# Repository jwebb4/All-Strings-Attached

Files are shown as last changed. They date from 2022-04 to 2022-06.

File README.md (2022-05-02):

# All-Strings-Attached
Senior Design Project under Dr. Abbott

Sponsership: Phil Westhart

### Team Members
Fall 2021 - Spring 2022: Carlos Rosales-Moran, Kimberly Tse, Joshua Webb

## Objective
**End Goal:** 
Determine the lifespan of strings on a string instrument
- First Iteration (Fall 2021-Spring 2022): Data Collection, provide foundation of mobile applicaiton

## Resources
**Mobile Application**
- ReactNative
- Expo Simulator (for debugging purposes)

**Microcontroller Programming**
- ArduinoIDE
- Special thanks to Neil Kolban for providing BLE libraries for the ESP32: Check out his repository: https://github.com/nkolban

## How to Use
Have the following in hand - we'll provide the documentation of how to set up
- Firebeetle IoT ESP32
- Wires & solder
- Wire stripper/cutter
- Pliers
- Proto-boards (optional)
- Tilt sensors
- AllStringsAttached mobile application

**Microcontroller SOFTWARE**
1. Download "All_Code_Put_Togehter.ino" into your desired directory. Make sure that it is nested underneath the folder with the same name.
2. Open the program using Arduino IDE
3. Compile & run :)

**Microcontroller HARDWARE**
1. Refer to the circuit schematic uploaded into this repo
2. Make sure to test each wiring when you solder. You can use a circuitboard to see whether it works!
3. Follow the circuit schematic and put the components together

**Microcontroller and Mobile Application **
1. Use the BLE scanner to check for the "Strings attached" device
2. Have fun!

## Future Implementation
- Update GUI of mobile application
- Collect data & attributes
- Develop string life prediction algorithm

## Acknowledgements
We would like to extend our deepest gratitude to those who have mentored, inspired, and/or guided us throughout this year-long project. We would like to first thank Dr. Rezaie for their mentorship and advice throughout the year, engineering technician Mr. Vernon Weir and Ms. Nicole Webb, and administrative coordinator Ms. Gail Jaszcz for helping us with the materials and operations of building our prototypes. We would also like to thank Mr. Don Bustos and Mr. Kevin Mendoza for their donation of strings.

Our deepest thanks to our customer, Phil Westhart, for providing the opportunity of implementing this project and for sharing his knowledge, guidance, and funding. Similarly, we would like to thank our mentor, Dr. Abbott, for guiding us throughout the project’s lifespan and for sharing the knowledge he has gained through several years of industry experience. Finally, we would like to thank all the other professors, students, and everyone that have shared their invaluable knowledge with us, since without them, we would not have sufficient knowledge to undergo this project.

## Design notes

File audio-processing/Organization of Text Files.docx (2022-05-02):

# Organization of Text Files

**Feel free to change naming – the attributes are harder to change tho.

# Naming

Ex. old-11282021-g.txt

- These are old strings (used and taken off from strings). You can change it to be something else.
- The recording is done on 11-28-2021
- We have a recording of the g string

# Attributes (What is inside the text files)

- instrument_type – What instrument is it? (Violin, viola, guitar, mandolin, etc.)
- instrument_size – What size is the instrument (Full size is 4/4 for violins, 7/8, ¾, etc.)
- num_strings_hold – How many strings does this instrument hold
- pitch – What is the letter sound of the pitch? (Middle C is C4, G3, A5, etc.)
- frequency – At what frequency is the pitch?
  - ** Sometimes they are tuned at the relative same pitch, but different frequencies. Some orchestras for example sometimes use 440Hz for an A, while others uses a 442Hz.
- string_core – What is the core of the string? (Synthetic, nylon, gut, steel, etc.)
- string_winding – If applicable, what winding around the core is the material? (Aluminum, silver, etc.)
- string_brand – What brand/company is the string from? (Pirastro, Thomastik, D’Addario)
- string_brand_version – From that string company, what string ‘version’ is it? (ProArte is made from D’ Addario, Vision Solos is made from Thomastik)
- string_guage – What is the tension of the strings (if applicable) (Options are light, medium, heavy)
- string_guage_value – What is the value of the string tension (per LBS)
- total_practice_time -- At the time of recording, how long were the strings practiced on?
- date_manufactured – When was this string manufactured? If applicable
- date_string_placed – When was this string placed onto the instrument?
- time_since_string_placed – How long has the strings been on the instrument
- has_capo – Does the instrument had a clip where it temporarily changes the pitch of the string (guitar) (Use 0 for no, 1 for yes)
- playing_style – What style is the instrument primarily played in
- percentage_other – How much do you think the string was played with an object? (bow, guitar pick, etc.)
- percentage_fingers – How much do you think the string was played with your fingers (plucking, strumming, etc.)
- sound_type – what kind of sound is being played in the audio? (Arco – long bow stroke, Pizz -- plucking sound)

All Strings Attached

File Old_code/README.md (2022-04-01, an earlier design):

This folder contains all the past versions of code and the parts of code which 
the current full version of this project are made of.

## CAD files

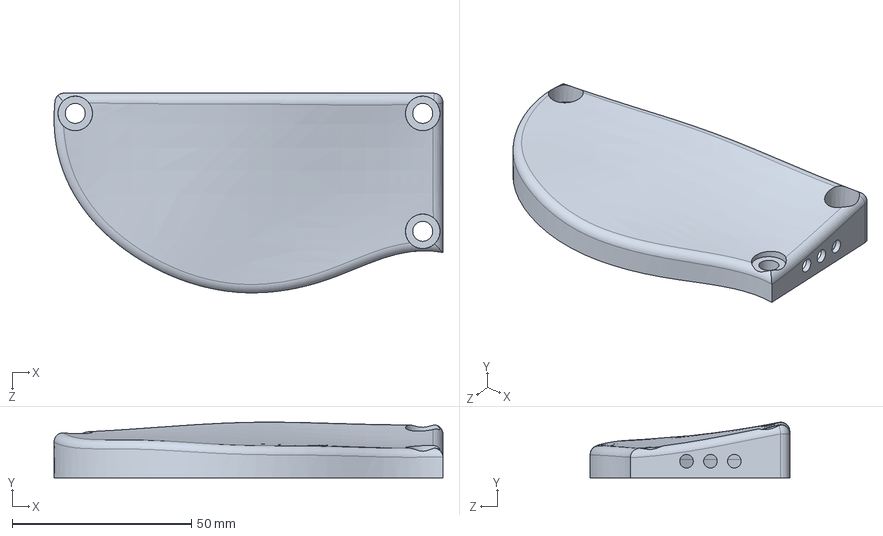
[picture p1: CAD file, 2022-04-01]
Current model curved lid/Model of thin curved lid.SLDPRT
108.5 x 15.6 x 55.7 mm

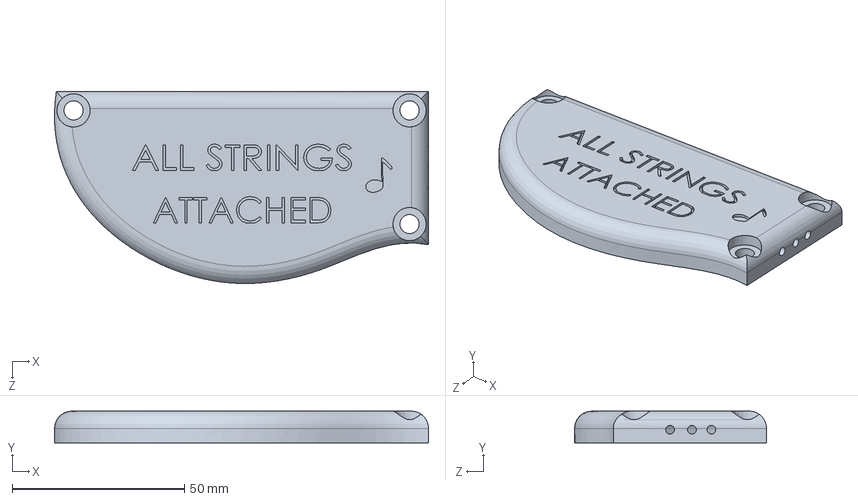
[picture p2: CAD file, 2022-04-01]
Current Model flat lid/model with flat thin lid.SLDPRT
108.5 x 9.21 x 55.7 mm

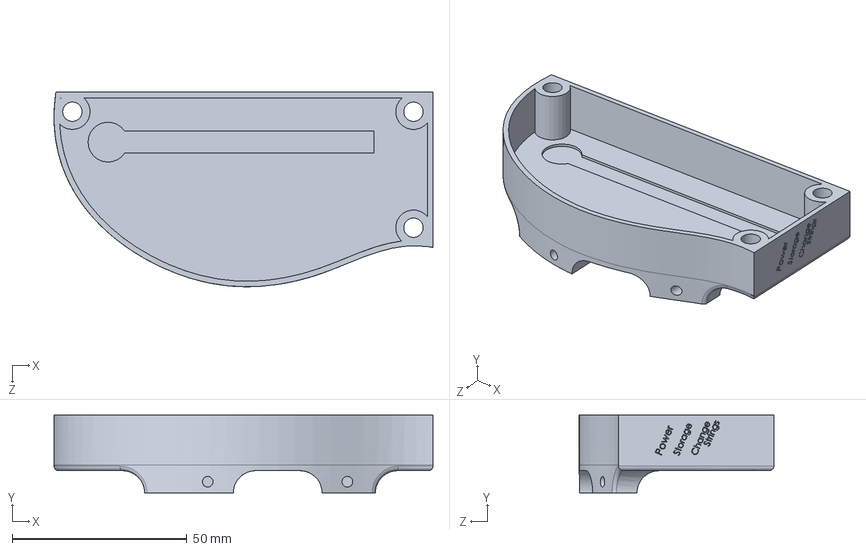
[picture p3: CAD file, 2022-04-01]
Current model curved lid/Model of base of device.SLDPRT
108.5 x 22.2 x 55.7 mm

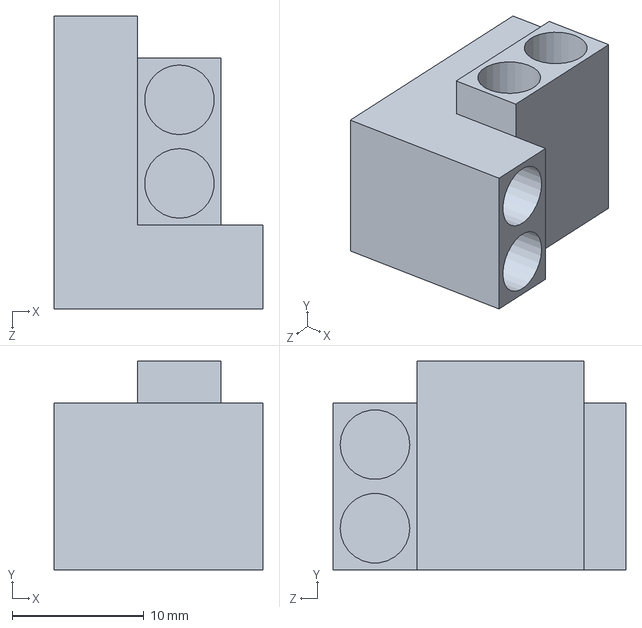
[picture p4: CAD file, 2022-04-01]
Current Model flat lid/tilt sensor holder.SLDPRT
15.9 x 15.9 x 22.2 mm

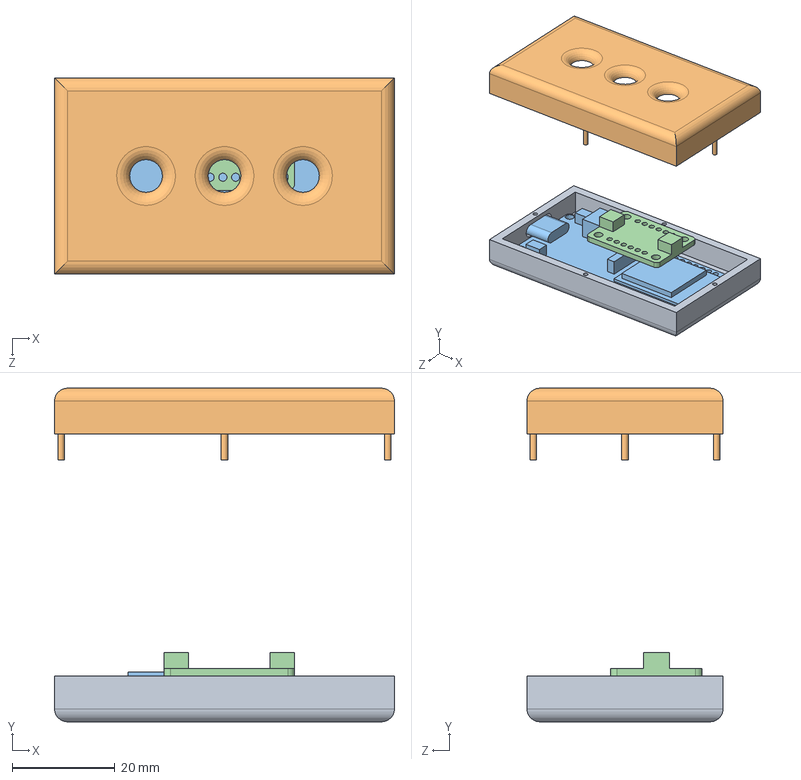
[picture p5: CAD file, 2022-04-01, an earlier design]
Old_models/First model/BoxAssembly.SLDASM
66.0 x 64.8 x 38.1 mm
Box-Bottom
Box-Top
micro
Accelerometer

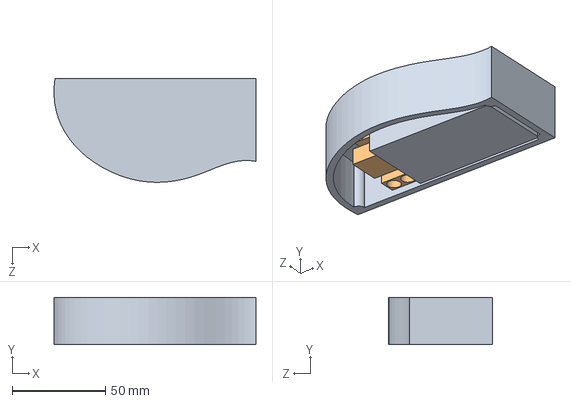
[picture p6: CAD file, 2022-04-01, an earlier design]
Old_models/Fourth model/start of fitting parts.SLDASM
108.5 x 25.4 x 55.7 mm
New device
tilt sensor holder

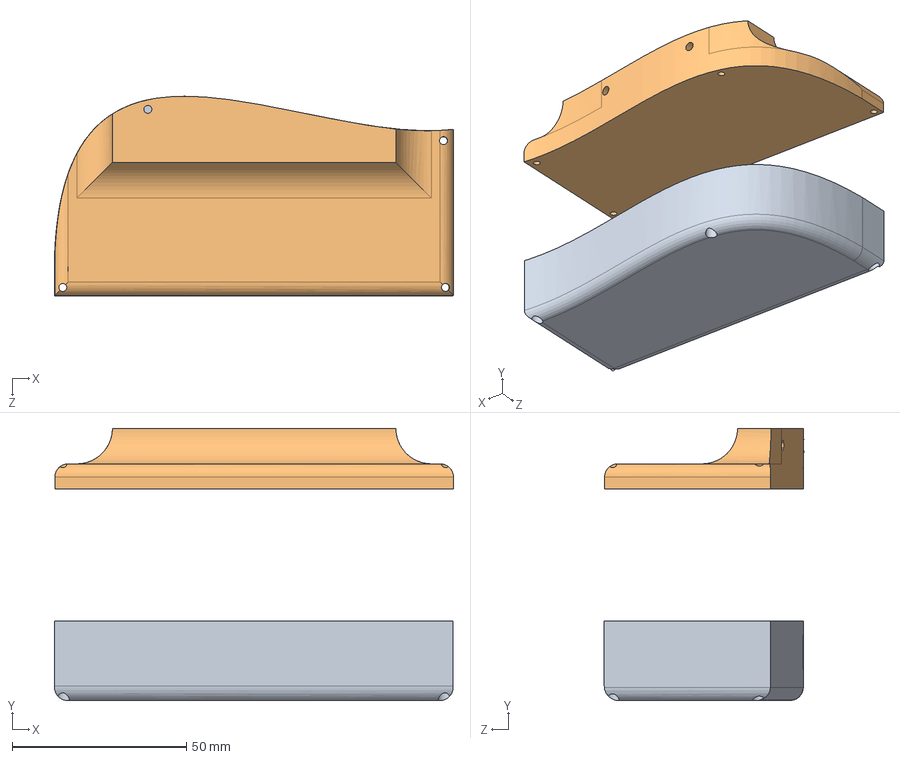
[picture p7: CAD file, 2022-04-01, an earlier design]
Old_models/Third model/device assembly.SLDASM
114.4 x 78.0 x 57.2 mm
device housing
Lid of device

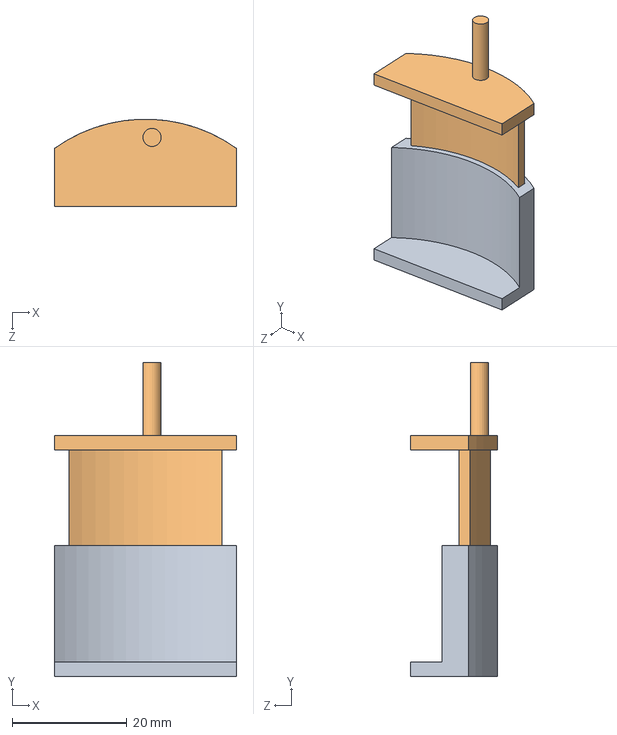
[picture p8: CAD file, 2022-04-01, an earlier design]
Old_models/First model/ClampAssembly.SLDASM
31.8 x 54.7 x 15.2 mm
Clamp-Bottom
Clamp-Top

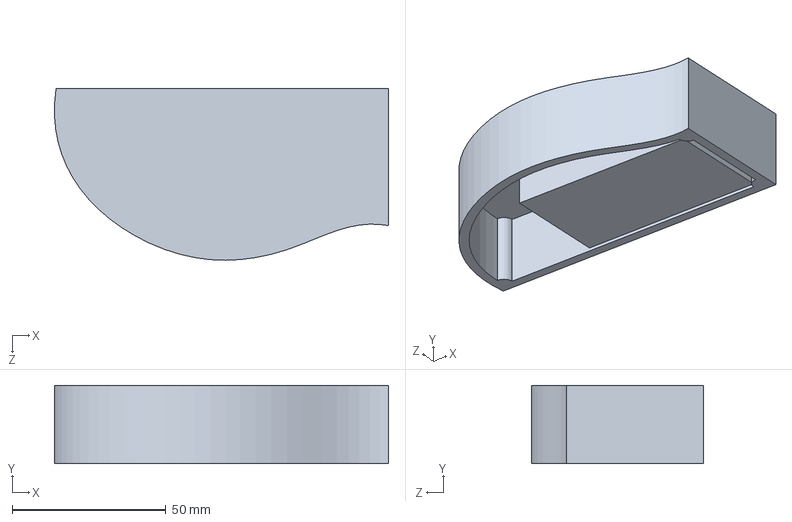
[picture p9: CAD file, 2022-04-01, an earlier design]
Old_models/Fourth model/New device.SLDPRT
108.5 x 25.4 x 55.7 mm

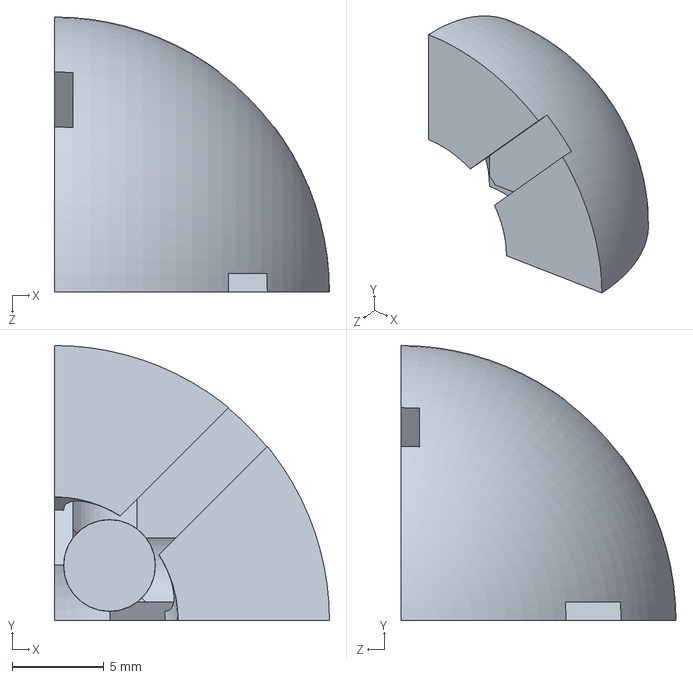
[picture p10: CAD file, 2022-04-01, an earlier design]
Old_models/Initial parts/Tilt sensor holder.SLDPRT
15.0 x 15.0 x 15.0 mm

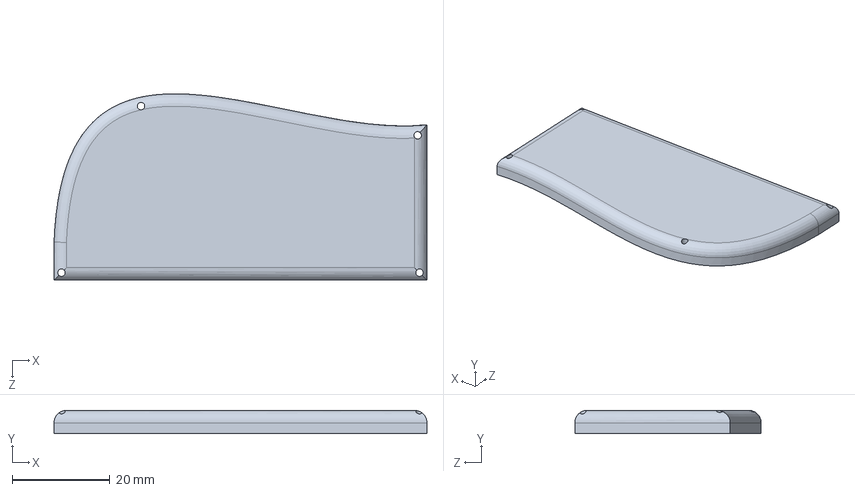
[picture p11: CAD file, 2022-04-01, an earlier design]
Old_models/Second model/Lid of device.SLDPRT
76.2 x 4.76 x 38.1 mm

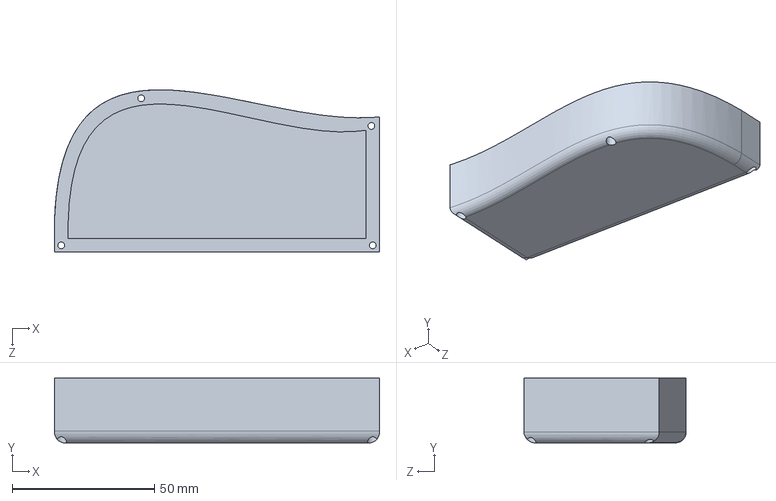
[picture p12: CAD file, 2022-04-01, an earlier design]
Old_models/Third model/device housing.SLDPRT
114.3 x 22.9 x 57.1 mm

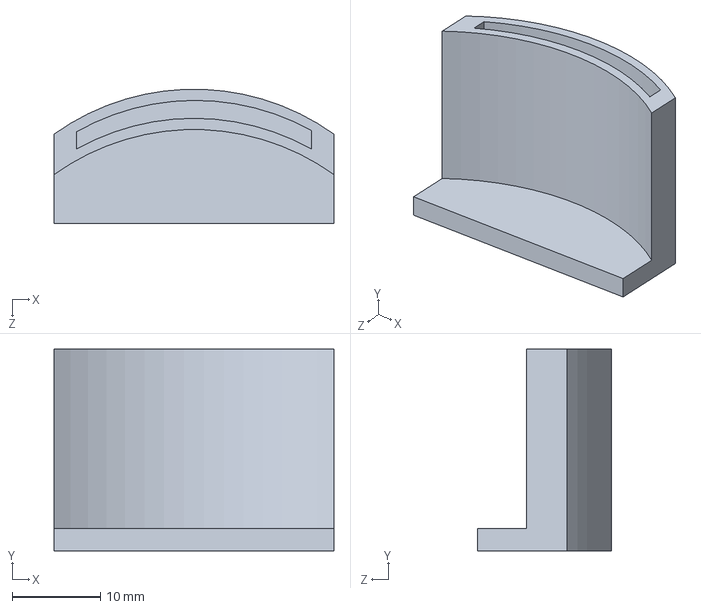
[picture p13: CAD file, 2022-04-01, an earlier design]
Old_models/First model/Clamp-Bottom.SLDPRT
31.8 x 22.9 x 15.2 mm

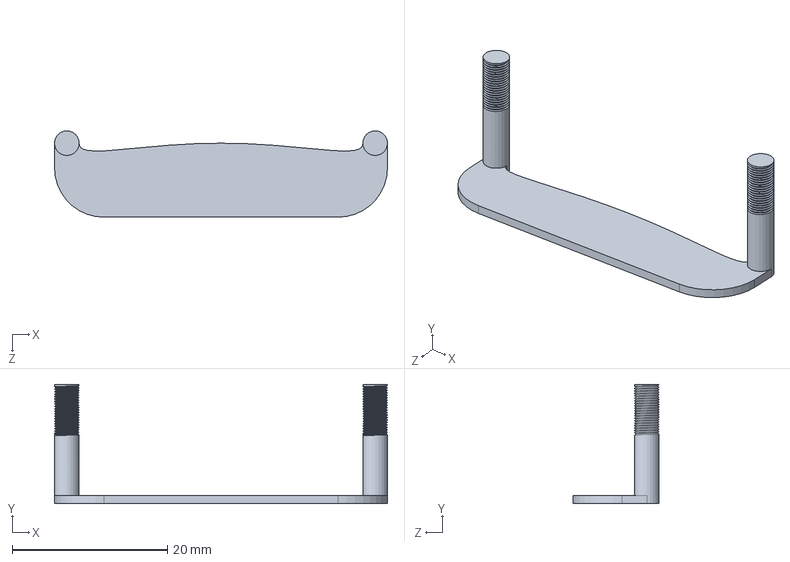
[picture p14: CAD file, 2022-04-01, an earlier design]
Old_models/Initial parts/2_Bottom_Clamp.SLDPRT
42.9 x 15.4 x 11.1 mm

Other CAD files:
Old_models/Second model/device housing.SLDPRT
Old_models/First model/Kim-practice.SLDPRT
Old_models/Fourth model/Top of device.STL
Current Model flat lid/model with flat thin lid.STL
Old_models/First model/Box-Bottom.SLDPRT
Old_models/First model/Box-Top.SLDPRT
Old_models/First model/Box.SLDPRT
Old_models/First model/Clamp-Top.SLDPRT
Old_models/Fourth model/Base of device.STL
Old_models/Fourth model/New lid.SLDPRT
Old_models/Fourth model/tilt sensor holder.STL
Old_models/Initial parts/2_Screw_Component.SLDPRT
Old_models/Initial parts/2_Top_Clamp.SLDPRT
Old_models/Initial parts/Accelerometer.SLDPRT
Old_models/Initial parts/micro.SLDPRT
Old_models/Third model/Lid of device.SLDPRT
Old_models/Third model/Lid of device.STL
Old_models/Third model/device housing.STL

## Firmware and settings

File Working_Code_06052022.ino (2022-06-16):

/*
All Strings Attached Program
  Team Members: Kimberly Tse, Joshua Webb, Carlos Rosales
  Team Advisor: Dr. Ben Abbott

  Purpose: Send time to the mobile application associated with this project whenever 
              it is connected && detects activity
           Save time to local memory whenver it is not connected && detects activity
  
*/


/* ------------------------------------------------------------------------------------------
 * Libraries used:
 *  sys/time.h - Get RTC time
 *  Preferences - Save into Flash memory
 *  BLEDevice - Provides functionality to build BLE server with characteristics.
 *  BLEServer - ...
 *  BLEUtils - ...
 *  BLE2902 - ...
 *  
 */

#include <arduinoFFT.h>
#include "driver/i2s.h"
#include <sys/time.h>
#include <Preferences.h>
#include <BLEDevice.h>
#include <BLEServer.h>
#include <BLEUtils.h>
//#include <BLE2902.h>

// FILLER FOR TILT SENSORS
#define Threshold 40

/* ------------------------------------------------------------------------------------------
 * DEFINE
 *  Storing timestamps in flash memory
 *  
 */
#define MAX_CHARS 15
#define MAX_LOCAL_STORAGE 50

/* ------------------------------------------------------------------------------------------
 * DEFINE
 *  Tilt Sensors usage based on pins
 *  
 */
#define x_sensor_pin 26   //D2
#define nx_sensor_pin 25 //D3
#define y_sensor_pin 34  //A3
#define ny_sensor_pin 35 //A2
#define z_sensor_pin 14  //D5
#define nz_sensor_pin 39  //A1

/* ------------------------------------------------------------------------------------------
 * DEFINE
 *  Microphone sampling rate and samples
 *  
 */

#define SAMPLES 512              //Must be a power of 2
#define SamplingRate 40000

/* ------------------------------------------------------------------------------------------
 * DEFINE
 *  Creating BLE server using Service / Char UUID
 *  
 */
#define bleServerName "Strings attached"
#define SERVICE_UUID        "4fafc201-1fb5-459e-8fcc-c5c9c331914b" // Currently using
#define dateCharacteristicUUID  "beb5483e-36e1-4688-b7f5-ea07361b26a8"
#define recentTimeCharacteristicUUID "688091db-1736-4179-b7ce-e42a724a6a68"

/* ------------------------------------------------------------------------------------------
 * Objects
 *  Preferences - API for saving data
 *  BLECharacteristic - API for creating a BLECharacteristic
 *  
 *  
 */
Preferences preferences;
BLEServer* pServer = NULL;
BLECharacteristic* dateCharacteristics = NULL;
BLECharacteristic* recentTimeCharacteristics = NULL;
BLECharacteristic* batteryCharacteristics = NULL;

/* ------------------------------------------------------------------------------------------
 * Preference Variables
 *  baseNameDataSpace - Namespace for saving each of the timestamps
 *  temp... - Temporarily stores a timestamp for computation of elapsed time
 *  pref_count - Getting the number of counts currently ready to store in what namespace
 *  cumulativeHr - Gets number of hours practice cumulatively to tell users whenever 
 *    they need to change strings
 *  
 */
String baseNameDataSpace = "dtStorage";
String tempStartData = "";
String tempEndData = "";
int pref_count = 1;
int cumulativeHr;

String translate = "";
static char timestamp[21];

String currentETString = "";
static char currentETCharArray[7]; // 6 + \n

/* ------------------------------------------------------------------------------------------
 * Behavioral States
 *  isTouched - locking mechanism to not spam touch 
 *  isStorageFull - Leads to special cases and interrupt
 *  isTransfer - checks to see if the transfer is complete
 */
bool isOn = false;
RTC_DATA_ATTR bool isStorageFull = false; // most liekly set a limit of 5 start/end saves
RTC_DATA_ATTR bool isTransfer = false;
RTC_DATA_ATTR int bootCount = 0; // 


/* ------------------------------------------------------------------------------------------
 * Timing Mechanism
 *  currentLoopCount - when uploading data, checks to see if what value we are uploading 
 */

int currentLoopCount = 1;

/* ------------------------------------------------------------------------------------------
 * Voltage measurments
 *  Each variable depicts the state of the tilt sensors 
 *  
 */
int voltage = 0;
float SampledVoltage = 0;
float lastVoltage = 0;
unsigned long SumVoltage = 0;
int voltageSample = 0;

/* ------------------------------------------------------------------------------------------
 * Tilt Sensor States
 *  Each variable depicts the state of the tilt sensors 
 *  
 */ 
unsigned long long BUTTON_PIN_BITMASK = 0x2000; //2^0 + 2^13 + 2^14 in Hex
int x_tilt = 0;
int y_tilt = 0;
int z_tilt = 0;
int nx_tilt = 0;
int ny_tilt = 0;
int nz_tilt = 0;
int x_lastState = 0;
int y_lastState = 0;
int z_lastState = 0;
int nx_lastState = 0;
int ny_lastState = 0;
int nz_lastState = 0;

/* ------------------------------------------------------------------------------------------
 * I2S Microphone
 * 
 *  
 */
const i2s_port_t I2S_PORT = I2S_NUM_0;
double vReal[SAMPLES];
double vRealMax;
double vImag[SAMPLES];
double StoredData[SAMPLES];
unsigned long newTime, oldTime;
unsigned int sampling_period_us;
int32_t SampleData;
uint8_t frequencyCount = 0;
int bytes_read;
bool StringPlaying = 0;
bool StringPlayingBuff = 0;

/* ------------------------------------------------------------------------------------------
 * Bluetooth States
 *  deviceConnected - state of whether microcontroller is connected to the mobile application
 *  oldDeviceConnected - whether we have connected to the same device as before
 *  firstConnection - whether it is the first transmission of data since connectivity 
 *    (repeats on each connection)
 *  first_use - relates to oldDeviceConnected
 *  isDeviceSettedUp - sets time of reference for microcontroller
 *  
 *  AllSensorsChecked - 
 *  SensorsChanged - 
 *  
 */

bool deviceConnected = false;
bool oldDeviceConnected = false;

bool firstConnection = false;

RTC_DATA_ATTR bool first_use = true;
RTC_DATA_ATTR bool isDeviceSettedUp = false;

bool AllSensorsChecked = 0;
bool SensorChanged = 0;

// touch_pad_t touchPin; ---

/* ------------------------------------------------------------------------------------------
 * RTC Counters and Interrupt Variables
 *  LED
 *  Sleep
 * 
 */
volatile int LEDInterruptCounter;
int totalLEDInterruptCounter;
hw_timer_t* LEDTimer = NULL;
portMUX_TYPE LEDTimerMux = portMUX_INITIALIZER_UNLOCKED;

volatile int Interupt_Counter = 0;
volatile int Microphone_Inactive = 0;
volatile int Microphone_Active = 0;
hw_timer_t* DeepSleepTimer = NULL;
portMUX_TYPE DeepSleepTimerMux = portMUX_INITIALIZER_UNLOCKED;

volatile int TransferInterruptCounter;
int totalTransferInterruptCounter;
hw_timer_t* TransferTimer = NULL;
portMUX_TYPE TransferTimerMux = portMUX_INITIALIZER_UNLOCKED;

volatile int BLEInterruptCounter;
int totalBLEInterruptCounter;
hw_timer_t* BLETimer = NULL;
portMUX_TYPE BLETimerMux = portMUX_INITIALIZER_UNLOCKED;

/* ------------------------------------------------------------------------------------------
 * TimeStruct
 *  This is to get the RTC timer
 * 
 */

struct tm getTimeStruct()
{
  struct tm timeinfo;
  getLocalTime(&timeinfo, 0);
  return timeinfo;
}

/* ------------------------------------------------------------------------------------------
 * CLASS: BLEServerCallbacks
 *  This is to determining whether the device is connected or not
 * 
 */
 
class MyServerCallbacks: public BLEServerCallbacks {
    void onConnect(BLEServer* pServer) {
      Serial.println("Connected!");
      deviceConnected = true;
      firstConnection = true;
    };

    void onDisconnect(BLEServer* pServer) {
      Serial.println("Disconnected!");
      deviceConnected = false;
      firstConnection = false;
      BLEInterruptCounter = 0;
      pServer->startAdvertising();
    }
};


/* ------------------------------------------------------------------------------------------
 * Interrupts - LED
 *  Behaviors when we hit an interrupt
 * 
 */
 
void IRAM_ATTR onLEDTimer() {
  portENTER_CRITICAL_ISR(&LEDTimerMux);
  LEDInterruptCounter++;
//--- Green light

  if((LEDInterruptCounter == 3 || LEDInterruptCounter == 6) && !StringPlayingBuff){
    digitalWrite(2,HIGH);
  } else if(!StringPlayingBuff){
    digitalWrite(2,LOW);
  }

//--- Yellow light     

  if(isStorageFull && (LEDInterruptCounter == 3 || LEDInterruptCounter == 6) && !StringPlayingBuff){
    digitalWrite(13,HIGH);
  } else if(!StringPlayingBuff){
    digitalWrite(13,LOW);
  }
    /*
     * Yellow LED code to blink
     */
    
//--- Red light    
  if(cumulativeHr >= 100 && (LEDInterruptCounter == 3 || LEDInterruptCounter == 6) && !StringPlayingBuff && SampledVoltage >= 1.7){
     
    digitalWrite(0,HIGH);
    if(deviceConnected){                          //  This portion
      // PROBLEM AREA -- Cannot do as it can conflict with other preference calls
      //preferences.begin("timeDifference", false); //  requires the user to tell 
      //preferences.clear();                        //  the device when strings
      //preferences.end();                          //  are changed
    }
    /*  
     * Red LED blinks
     */
    }  else if (!StringPlayingBuff) {
      digitalWrite(0,LOW);
    }
  
  if(SampledVoltage < 1.7 && (LEDInterruptCounter == 3 || LEDInterruptCounter == 6) && !StringPlayingBuff){
    digitalWrite(0,HIGH);
  } else if(!StringPlayingBuff){
    digitalWrite(0,LOW);
  }

//--- String Playing   
  
  if (StringPlayingBuff && LEDInterruptCounter == 2) {
      digitalWrite(2,HIGH);
      digitalWrite(13,LOW);
      digitalWrite(0,LOW);
  } else if (StringPlayingBuff && LEDInterruptCounter == 4) {
      digitalWrite(2,LOW);
      digitalWrite(13,HIGH);
      digitalWrite(0,LOW);
  } else if (StringPlayingBuff && LEDInterruptCounter == 6) {
      digitalWrite(2,LOW);
      digitalWrite(13,LOW);
      digitalWrite(0,HIGH);
  }

  if(LEDInterruptCounter == 6){
    LEDInterruptCounter = 0;
  }
  portEXIT_CRITICAL_ISR(&LEDTimerMux);
}

/* ------------------------------
 * 
 */
void IRAM_ATTR onTransferTimer() {
  portENTER_CRITICAL_ISR(&TransferTimerMux);
  TransferInterruptCounter++;
  if(deviceConnected && (isStorageFull || pref_count > 1)){
    isTransfer = true;
  }
  portEXIT_CRITICAL_ISR(&TransferTimerMux);
}

/* ------------------------------------------------------------------------------------------
 * Interrupts - DeepSleep
 *  Behaviors when we hit an interrupt
 * 
 */
void IRAM_ATTR onDeepSleepTimer() {
  portENTER_CRITICAL_ISR(&DeepSleepTimerMux);
  Interupt_Counter++;
  Microphone_Inactive++;

  if(StringPlaying) {
    Microphone_Active++;
    Microphone_Inactive = 0;
    if (Microphone_Active >= 1) {
      StringPlayingBuff = 1;
    }
  } else if(Microphone_Inactive >= 3){
    StringPlayingBuff = 0;
  } else {
    Microphone_Active = 0;
  }
  // Serial.println("InactiveCount: " + String(Interupt_Counter));
  if (StringPlaying) {
    Interupt_Counter = 0;
  }
  else if (Interupt_Counter >= 300) {
//      Serial.println("start deep sleep");
      
       esp_deep_sleep_start(); // just for video
  }
  portEXIT_CRITICAL_ISR(&DeepSleepTimerMux);
}

/* ------------------------------------------------------------------------------------------
 * Interrupts - BLEConnect
 *  Behaviors when we hit an interrupt
 * 
 */
void IRAM_ATTR onBLETimer() {
  portENTER_CRITICAL_ISR(&BLETimerMux);
  if(isOn == false){
    BLEInterruptCounter++;
  }
  Serial.println(String(BLEInterruptCounter));
  if (deviceConnected && BLEInterruptCounter >= 50) {
     Serial.println("Auto-Disconnect");
     pServer->disconnectClient();
  }
  portEXIT_CRITICAL_ISR(&BLETimerMux);
}

/* -----------------------------------------------------------------------------------------------------------------------------------
 * Procedure - MicophoneCheck
 *  Checks for violin/string sounds with multiple pressent frequencies
 * 
 */

  arduinoFFT FFT = arduinoFFT();

 void micCheck(){
   for (int i = 0; i < SAMPLES; i++)
  {
    
    newTime = micros() - oldTime;
    oldTime = newTime;
    SampleData = 0;
    bytes_read = i2s_pop_sample(I2S_PORT, (char *)&SampleData, portMAX_DELAY); // no timeout
    vReal[i] = SampleData/10;
    StoredData[i] = SampleData;
    vImag[i] = 0;
    while (micros() < (newTime + sampling_period_us))
    {
      delay(0);
    }
  }
  FFT.Windowing(vReal, SAMPLES, FFT_WIN_TYP_HANN, FFT_FORWARD);
  FFT.Compute(vReal, vImag, SAMPLES, FFT_FORWARD);

  for(uint16_t i = 0; i < SAMPLES; i++){
    vReal[i] = sqrt(sq(vReal[i]) + sq(vImag[i]));
  }

  StringPlaying = 0;
  frequencyCount = 0;
  vRealMax = 0;
  for(int i = 0; i < SAMPLES; i++){             // Band pass filter
      if(i < 2 || i >= 130){
        vReal[i] = 0;
      }
      else if(vReal[i] < 50000000){
        vReal[i] = 0;
      }
      if (vReal [i] > vRealMax && i >=2 && i < 130) {
          vRealMax = vReal[i];
        }
      if (vReal[i] != 0 && vReal[i+2] < vRealMax * .26) {// was .26
        frequencyCount++;
      }
      if(frequencyCount > 5) {
        StringPlaying = 1;
      }
    }
    // Serial.print(StringPlayingBuff);
    // Serial.print("\t");
    // Serial.println(StringPlaying);
 }
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
void loop() {
  // Get current time
  //time_t timeNow;
  struct tm timeinfo = getTimeStruct();

  //time(&timeNow);
  //localtime_r(&timeNow, &timeinfo);
 
  x_tilt = digitalRead(x_sensor_pin); // 0x00200000
  y_tilt = analogRead(y_sensor_pin); // 0x00400000
  z_tilt = digitalRead(z_sensor_pin); // 0x0001
  nx_tilt = digitalRead(nx_sensor_pin); // 0x4000
  ny_tilt = analogRead(ny_sensor_pin); // 0x2000
  nz_tilt = analogRead(nz_sensor_pin); // 0x0004   

  // Check sensors
  SensorCheck();
  micCheck();
  voltageRead();

  /* Case 1 - Device is Connected and Storage is not Full*/
  if (deviceConnected) {
    timerAlarmEnable(BLETimer);
    
    /* Get Start Time Stamp */
    if(StringPlayingBuff && !isOn){
      Serial.println("Connected - Start");
      isOn = true;
      
      timerAlarmDisable(BLETimer);
      BLEInterruptCounter = 0;
      
        Serial.println("DeviceConnected :: Start Touch");
        // isTouched = true; ---

        // Get startTime
        translate = GetCurrentTMStamp(timeinfo.tm_year, 
                                        timeinfo.tm_mon, 
                                        timeinfo.tm_mday, 
                                        timeinfo.tm_hour,
                                        timeinfo.tm_min,
                                        timeinfo.tm_sec);
                                        
        // Convert to char array, used for later
        translate.toCharArray(timestamp, translate.length() + 1);
       //  Serial.println("Start touch"); ---
       //  Serial.println(timestamp); ---

        // Save String tempStart so that we can calculate elapsedTime
        tempStartData = timestamp;
      
    }

    /* Get End Time, Compute Elapsed Time, Send startTime & elapsedTime */
    if(!StringPlayingBuff && isOn){
      isOn = false;    

        // isTouched = false; ---
        Serial.println("Connected - End");
        
        // Get endTime
        translate = GetCurrentTMStamp(timeinfo.tm_year, 
                                          timeinfo.tm_mon, 
                                          timeinfo.tm_mday, 
                                          timeinfo.tm_hour,
                                          timeinfo.tm_min,
                                          timeinfo.tm_sec);

        // convert to char array, save for later
        static char tempEndArr[20];
        translate.toCharArray(tempEndArr, translate.length() + 1);
        tempEndData = tempEndArr;

        // Get cumulative hour, also saves elapsed time
        cumulativeHr = CalculateTimeElapsed(tempStartData, tempEndData);
        currentETString.toCharArray(currentETCharArray, currentETString.length() + 1);

        // Concatenate startTime and elapsedTime
        strcat(timestamp,currentETCharArray);

        Serial.println(tempStartData);
        Serial.println(currentETCharArray);
        Serial.println(timestamp);

        // Send data to mobile application
        dateCharacteristics->setValue(timestamp);
        dateCharacteristics->notify();

    }
    
    /* Sending data, clearing data*/    
    if((isStorageFull || pref_count > 1) && isTransfer){
      Serial.println("Transferring local data");
      if(currentLoopCount == 1){
        delay(1000);
      }
      char timeSent[20];

      // Getting name storage
      String namingStorage = baseNameDataSpace + String(currentLoopCount);
      int name_length = namingStorage.length() + 1;
      char nameData[name_length];
      namingStorage.toCharArray(nameData,name_length);

      // Getting data to send and clear
      preferences.begin(nameData, false);
      String timeString = preferences.getString("date","nodate");
      preferences.end();
      
      int timeStringLength = timeString.length() + 1;
      timeString.toCharArray(timeSent,timeStringLength);

      // Send data
      dateCharacteristics->setValue(timeSent);
      dateCharacteristics->notify();

      // Clear specified storage
      preferences.begin(nameData, false);
      preferences.clear();
      preferences.end();

      // Serial.println(nameData);
      
      currentLoopCount++;

      if(currentLoopCount >= pref_count){
        ClearPrefCount();
        isStorageFull = false;
        currentLoopCount = 1;
      }
      isTransfer = false;
    }

    /* Connecting after disconnect  */
    if(firstConnection){
      delay(1000);
      BLEInterruptCounter = 0;
      String recentTimeStamp = GetCurrentTMStamp(timeinfo.tm_year, 
                                          timeinfo.tm_mon, 
                                          timeinfo.tm_mday, 
                                          timeinfo.tm_hour,
                                          timeinfo.tm_min,
                                          timeinfo.tm_sec);
      char rtsChar[15];
      
      recentTimeStamp.toCharArray(rtsChar, recentTimeStamp.length() + 1);
      recentTimeCharacteristics->setValue(rtsChar);
      recentTimeCharacteristics->notify(); 
      Serial.println("Most Recent Time: " + String(rtsChar));
      firstConnection = false;
      
    }
    if(cumulativeHr >= 100 && (LEDInterruptCounter == 3 || LEDInterruptCounter == 6) && !StringPlayingBuff && SampledVoltage >= 1.7){
      preferences.begin("timeDifference", false); //  requires the user to tell 
      preferences.clear();                        //  the device when strings
      preferences.end();                          //  are changed

    }
  }

  /* Case 2 - Device is not connected && Storage is not full*/
  if(!deviceConnected && !isStorageFull){
    timerAlarmDisable(BLETimer);
    /* Get startTime */
    if(StringPlayingBuff && !isOn){
      Serial.println("Disconnected - Start");
        isOn = true;
        // isTouched = true; ---
        Serial.println("!DeviceConnected :: Start Touch");

        // Get start timestamp
        translate = GetCurrentTMStamp(timeinfo.tm_year, 
                                        timeinfo.tm_mon, 
                                        timeinfo.tm_mday, 
                                        timeinfo.tm_hour,
                                        timeinfo.tm_min,
                                        timeinfo.tm_sec);
                                        
        // Convert to char array
        translate.toCharArray(timestamp, translate.length() + 1);

        // Save tempStart so that we can calculate elapsedTime
        tempStartData = timestamp;
      
    }

    /* Get endTime*/
    if(!StringPlayingBuff && isOn){
      Serial.println("Disconnected - End");
        isOn = false;
      
        // isTouched = false; ---
        Serial.println("!DeviceConnected :: End Touch");

        // Creating datastorage for startTime, elapsedTime
        String namingStorage = baseNameDataSpace + String(pref_count);
        int name_length = namingStorage.length() + 1;
        char nameData[name_length];
        namingStorage.toCharArray(nameData,name_length);

        // Getting end time to calculate elapsedTime
        translate = GetCurrentTMStamp(timeinfo.tm_year, 
                                          timeinfo.tm_mon, 
                                          timeinfo.tm_mday, 
                                          timeinfo.tm_hour,
                                          timeinfo.tm_min,
                                          timeinfo.tm_sec);

        // Conversion to char array
        static char tempEndArr[20];
        translate.toCharArray(tempEndArr, translate.length() + 1);
        tempEndData = tempEndArr;

        // Get cumulative hour, also saves elapsed time
        cumulativeHr = CalculateTimeElapsed(tempStartData, tempEndData);
        currentETString.toCharArray(currentETCharArray, currentETString.length() + 1);

        // Concatenates startTime and elapsedTime
        strcat(timestamp,currentETCharArray);

        // Saving timestamp into flash
        preferences.begin(nameData, false);
        preferences.putString("date", timestamp);
        preferences.end();

        IncrementPrefCount();

        Serial.println(nameData);
        Serial.println(timestamp);
        
        //Serial.println("Count: " + String(pref_count));
        if(pref_count > MAX_LOCAL_STORAGE){
          isStorageFull = true;
        
      }
    }
    // Stop sending mostRecentTimeCharacteristic value
    if(!firstConnection){
      firstConnection = true; 
    }   
  }
  
}

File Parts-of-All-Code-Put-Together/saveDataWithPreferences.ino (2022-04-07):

/*
 ESP32 startup counter example with Preferences library.

 This simple example demonstrates using the Preferences library to store how many times the ESP32 module has booted. 
 The Preferences library is a wrapper around the Non-volatile storage on ESP32 processor.

 created for arduino-esp32 09 Feb 2017 by Martin Sloup (Arcao)
 
 Complete project details at https://RandomNerdTutorials.com/esp32-save-data-permanently-preferences/
*/
#include <sys/time.h>

// yyyymmddhhmmssF
//#include <TimeLib.h>
#include <Preferences.h>
#include <BLEDevice.h>
#include <BLEServer.h>
#include <BLEUtils.h>
#include <BLE2902.h>

#define Threshold 40
#define MAX_CHARS 15
#define MAX_LOCAL_STORAGE 10


// #define CHARACTERISTIC_UUID "beb5483e-36e1-4688-b7f5-ea07361b26a8" // still in use but need to switch
#define SERVICE_UUID        "4fafc201-1fb5-459e-8fcc-c5c9c331914b" // Currently using
#define dateCharacteristicUUID  "c84b5feb-a12f-45bb-a3ff-a6adce24f69e"
#define batteryCharacteristicUUID   "59d74fba-0f2b-4741-a057-d053662f2abe"

Preferences preferences;
/* Data stored in flash
 *  timestamps
 *  cumulativeElapsedTime
 *  TBA current count
 * 
 */
BLECharacteristic dateCharacteristics("c84b5feb-a12f-45bb-a3ff-a6adce24f69e",BLECharacteristic::PROPERTY_NOTIFY);
BLEDescriptor dateDescriptor(BLEUUID((uint16_t)0x2902));

String timeDifference = "timeDifference";
String baseNameDataSpace = "dtStorage";
String tempStartData = "";
String tempEndData = "";
int count = 1;

bool isTouched = false;
bool isStorageFull = false; // most liekly set a limit of 5 start/end saves
bool isReadySendData = false;
bool isClearingData = false;

volatile int interruptCounter;
int totalInterruptCounter;
int minutes;
int timeActive;

int cumulativeHr;

String translate = "";
double dateValue;

bool deviceConnected = false;
bool oldDeviceConnected = false;

RTC_DATA_ATTR bool isDeviceSettedUp = false;

touch_pad_t touchPin;
hw_timer_t * timer = NULL;
portMUX_TYPE timerMux = portMUX_INITIALIZER_UNLOCKED;

struct tm getTimeStruct()
{
  struct tm timeinfo;
  getLocalTime(&timeinfo, 0);
  return timeinfo;
}

class MyServerCallbacks: public BLEServerCallbacks {
    void onConnect(BLEServer* pServer) {
      deviceConnected = true;
    };

    void onDisconnect(BLEServer* pServer) {
      deviceConnected = false;
    }
};


void IRAM_ATTR onTimer() {
  portENTER_CRITICAL_ISR(&timerMux);
  interruptCounter++;
  portEXIT_CRITICAL_ISR(&timerMux);
}


void callback(){
}

#define startTime // need to make this a continuous loop
#define bleServerName "Strings attached"


String GetCurrentTMStamp(int yearTM, int monthTM, int dayTM, 
 int hourTM, int minTM, int secTM){
  String fYear = "";
  String fMonth = "";
  String fDay = "";
  String fHr = "";
  String fMin = "";
  String fSec = "";

  yearTM += 1900;
  monthTM += 1;
  minTM -= 18;
  Serial.println("Year " + String(yearTM));
  Serial.println("Month " + String(monthTM));
  Serial.println("Day " + String(dayTM));
  Serial.println("Hour " + String(hourTM));
  Serial.println("Min " + String(minTM));
  Serial.println("Sec " + String(secTM));
  //monthTM += 1;
  fYear = String(yearTM);
  if(monthTM < 10 ){
    fMonth = "0" + String(monthTM);
  } else {
    fMonth = String(monthTM);
  }
  if(dayTM < 10){
    fDay = "0" + String(dayTM);
  } else{
    fDay = String(dayTM);  
  }
  if(hourTM < 10){
    fHr = "0" + String(hourTM);
  } else{
    fHr = String(hourTM);  
  }
  if(minTM < 10){
    fMin = "0" + String(minTM);
  } else{
    fMin = String(minTM);  
  }
  if(secTM < 10){
    fSec = "0" + String(secTM);
  } else{
    fSec = String(secTM);  
  }
  return fYear + fMonth + fDay + fHr + fMin + fSec;                           
}

int CalculateTimeElapsed(String tStart, String tEnd){
  // Getting variables
  String sYearStr = String(tStart.charAt(0)) + String(tStart.charAt(1)) + String(tStart.charAt(2)) + String(tStart.charAt(3));
  String sMonthStr = String(tStart.charAt(4)) + String(tStart.charAt(5));
  String sDayStr = String(tStart.charAt(6)) + String(tStart.charAt(7));
  String sHrStr = String(tStart.charAt(8)) + String(tStart.charAt(9));
  String sMinStr = String(tStart.charAt(10)) + String(tStart.charAt(11));
  String sSecStr = String(tStart.charAt(12)) + String(tStart.charAt(13));
  
  String eYearStr = String(tEnd.charAt(0)) + String(tEnd.charAt(1)) + String(tEnd.charAt(2)) + String(tEnd.charAt(3));
  String eMonthStr = String(tEnd.charAt(4)) + String(tEnd.charAt(5));
  String eDayStr = String(tEnd.charAt(6)) + String(tEnd.charAt(7));
  String eHrStr = String(tEnd.charAt(8)) + String(tEnd.charAt(9));
  String eMinStr = String(tEnd.charAt(10)) + String(tEnd.charAt(11));
  String eSecStr = String(tEnd.charAt(12)) + String(tEnd.charAt(13));

  int sYear = sYearStr.toInt();
  int sMonth = sMonthStr.toInt();
  int sDay = sDayStr.toInt();
  int sHr = sHrStr.toInt();
  int sMin = sMinStr.toInt();
  int sSec = sSecStr.toInt();
  
  Serial.println(tStart);
  Serial.println("Start: " + sYearStr + " " + sMonthStr + " " + sDayStr + " " + sHrStr + " " + sMinStr + " " + sSecStr);

  int eYear = eYearStr.toInt();
  int eMonth = eMonthStr.toInt();
  int eDay = eDayStr.toInt();
  int eHr = eHrStr.toInt();
  int eMin = eMinStr.toInt();
  int eSec = eSecStr.toInt();

  Serial.println(tEnd);
  Serial.println("End: " + eYearStr + " " + eMonthStr + " " + eDayStr + " " + eHrStr + " " + eMinStr + " " + eSecStr);
  
  preferences.begin("timeDifference", false);
  int prevEH = preferences.getInt("elapsedHour", 0);
  int prevEM = preferences.getInt("elapsedMin", 0);
  int prevES = preferences.getInt("elapsedSec", 0);

  Serial.println("PrevEH: " + String(prevEH));
  Serial.println("PrevEM: " + String(prevEM));
  Serial.println("PrevES: " + String(prevES));
  
  int currentES = 0;
  int currentEM = 0;
  int currentEH = 0;
  int carryMin = 0;
  int carryHr = 0;

  // Determining current elapsed time
  if(eSec - sSec < 0){
    currentES = 60 - (sSec - eSec);
    carryMin = 1;
  } else{
    currentES = eSec - sSec;
  }
  if((eMin - sMin - carryMin )< 0){
    currentEM = 60 - carryMin - (sMin - eMin);
    carryHr = 1;
  } else{
    currentEM = eMin - sMin - carryMin;
  }
  if((eHr - sHr - carryHr) < 0){
    currentEH = 24 - carryHr - (sHr - eHr);
  } else{
    currentEH = eHr - sHr - carryHr;
  }

  Serial.println("CurrEH: " + String(currentEH));
  Serial.println("CurrEM: " + String(currentEM));
  Serial.println("CurrES: " + String(currentES));
  
  // Adding to CumulativeSum
  int finES;
  int finEM;
  int finEH;
  int carry = 0;

  if(currentES + prevES > 59){
    finES = (currentES + prevES) % 60;
    carry = (currentES + prevES) / 60;
  } else{
    finES = currentES + prevES;
    carry = 0;
  }
  if(currentEM + prevEM + carry> 59){
    finEM = (currentEM + prevEM + carry) % 60;
    carry = (currentEM + prevEM + carry) / 60;
  } else{
    finEM = currentEM + prevEM + carry;
    carry = 0;
  }
  finEH = currentEH + prevEH + carry;
  carry = 0;
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

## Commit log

2022-04-07 Fixed cumulative elapsed time arithmetic
    [saveDataWithPreferences.ino]
2022-04-12 Implemented behavior states, interrupt
2022-04-12 Debugged Preference data bug - not saving
    Also added feature of sending local data upon connection regardless of how many saves
    [All_Code_Put_Together.ino]
2022-04-13 Fixed elapsedTime and timestamps pref storage
    [All_Code_Put_Together.ino]
2022-04-19 Added multiple timer interrupts for -deepsleep & - transferdata
2022-04-30 hopefullly fixxed cpu crashes
    [All_Code_Put_Together.ino]
2022-05-02 Supplemental library to edit files via Audacity
    [fontconfig.txt]
2022-05-03 Update All_Code_Put_Together.ino
    Added low battery indicator and fixed microphone buffer
    [All_Code_Put_Together.ino]
2022-06-06 Updated BLE interrupt so that there is no need to reconnect twice
